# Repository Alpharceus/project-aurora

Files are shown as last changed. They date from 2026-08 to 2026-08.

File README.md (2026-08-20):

# Aurora — Wake-on-LAN over WiFi with a WT32-ETH01

Wake a sleeping PC from anywhere on your WiFi (and later, from anywhere at all)
using an inexpensive ESP32 board with a built-in Ethernet jack. Since v2 the
same board also detects your phone's presence over BLE — walk in the door
after being away and the tower wakes itself, no app running on the phone.

```
phone/laptop → WiFi → HTTP /wake?token=… → WT32-ETH01 → magic packet → PC's wired NIC
```

The WT32-ETH01 (ESP32 + LAN8720 PHY) runs both network stacks at once:
its **WiFi** side joins your home network and serves two authenticated HTTP
endpoints; its **Ethernet** side is cabled point-to-point into the PC's wired
NIC and is the only place the magic packet ever goes.

## Why this shape

- **The PC's WiFi can't do it.** Most consumer WiFi NICs have no working
  WoWLAN. The wake packet must arrive on the wired NIC.
- **Point-to-point, no switch needed.** The PC's Ethernet port connects
  directly to the board. No DHCP, no IP config on the PC side — a sleeping
  NIC matches the magic packet **in hardware at layer 2**; it never consults
  the IP stack.
- **The static-subnet trick.** The firmware pins a static subnet
  (`192.168.50.1/24`) to the ETH interface and sends the wake packet to that
  subnet's broadcast address. That forces the packet out the wire instead of
  the WiFi interface. (Stock ESPHome can't run WiFi + ETH simultaneously —
  hence plain Arduino.)
- **10/100 is fine.** NICs renegotiate down to 10/100 in sleep anyway.

## Hardware

What we actually used:

- [WT32-ETH01 board](https://www.amazon.com/dp/B0HB3B557Z) (ESP32 + LAN8720
  Ethernet)
- [CP2102 USB-UART dongles, 2-pack](https://www.amazon.com/dp/B0GWVV83SK) —
  one for the first (serial) flash, one living in a USB wall charger as the
  permanent power supply. After the first flash, updates go over WiFi (OTA)
  and the data dongle retires.
- Jumper wires, one Ethernet cable, a USB wall charger.

## Enclosure

Printable case for the WT32-ETH01: `aurora_box_body.stl` + `aurora_box_lid.stl`.
Any plastic works (ours is PLA) — plastic is transparent to both the WiFi/BLE
radio and, if you later add an mmWave sensor, its 24 GHz radar; just keep
metallic filament and foil out of the build. Leave openings for the Ethernet
jack and the power leads.

## Setup

### 1. Prepare the firmware

```
copy aurora_wake.example.ino aurora_wake/aurora_wake.ino
```

(The folder must be named `aurora_wake` — Arduino tooling requires the sketch
directory to match the sketch name.) Fill in the four values at the top:
2.4 GHz SSID + password, a long random token, and the PC's wired-NIC MAC
(`getmac /v` on Windows). **Never commit the filled-in copy** — this repo's
`.gitignore` is default-deny for that reason.

### 2. Arm the PC's NIC (Windows)

- Device Manager → the wired NIC → Power Management: allow this device to
  wake the computer, **magic packet only**.
- Advanced tab (or `Set-NetAdapterAdvancedProperty`): *Wake on Magic Packet*
  = Enabled, *Wake on pattern match* = **Disabled** (pattern wake causes
  spurious wakeups), *Shutdown Wake-On-Lan* = Enabled.
- Verify: `powercfg /devicequery wake_armed` must list the NIC.
- Disarm wake sources you don't want (we disarmed the WiFi NIC:
  `powercfg /devicedisablewake "<device name>"`), so wake attribution stays
  clean.
- Check Fast Startup is off (`HiberbootEnabled = 0`) — it breaks
  WoL-from-shutdown semantics on many systems.
- If the Ethernet port has a leftover static IP, remove it. The link needs
  **no** PC-side IP config at all, and less surface is better.

### 3. Toolchain

```
arduino-cli config init
arduino-cli config add board_manager.additional_urls https://espressif.github.io/arduino-esp32/package_esp32_index.json
arduino-cli core update-index
arduino-cli core install esp32:esp32
arduino-cli lib install NimBLE-Arduino
arduino-cli compile --fqbn esp32:esp32:wt32-eth01:PartitionScheme=min_spiffs aurora_wake
```

Two dependencies: the esp32 core (bundles `ETH.h`, `WiFi.h`, `WiFiUdp.h`,
`WebServer.h`, `ArduinoOTA.h`, `Preferences.h`, mbedtls) and NimBLE-Arduino
for the v2 presence scanning.

**The partition scheme matters and cannot change over OTA.** The default
scheme has 1.25MB app slots; the v2 sketch is ~1.29MB and won't fit. Set
`PartitionScheme=min_spiffs` (1.9MB slots) at the **first serial flash** —
if you flashed with defaults, you get exactly one more date with the UART
dongle. (Don't trust the compile output's "Maximum is 8388608 bytes" under
the default scheme — that's a boards.txt bug; the real slot is 1.25MB.)

### 4. First flash (serial — the board has no USB port)

Wiring, with the board **unpowered**:

| Dongle (data) | WT32-ETH01 |
|---|---|
| TX | **RX0** (not RXD!) |
| RX | **TX0** (not TXD!) |
| GND | GND (any GND pin) |
| 5V | **5V pin** (see gotcha #3)  |

Then: jumper **IO0 → GND**, apply power (IO0 is sampled only at power-on),
and:

```
arduino-cli upload --fqbn esp32:esp32:wt32-eth01:PartitionScheme=min_spiffs -p COM7 aurora_wake
```

Afterward: power off, remove the IO0 jumper, power on. Watch the serial line
at 115200 baud — you should see boot ROM output, dots while WiFi connects,
then the IP.

### 5. Smoke test

- `http://<board-ip>/status` → `aurora up`, firmware version, WiFi IP,
  `eth link: up/down`.
- `/wake` with no/wrong token → 403. With the token → 200 and the packet
  fires (it also self-reports if the ETH link is down).
- Give the board a **DHCP reservation** in your router so the IP never
  drifts.

### 6. Ethernet leg

Cable the board to the PC's port. `/status` should report `eth link: up` —
**including while the PC sleeps** (the NIC keeps the PHY alive). If the link
drops in sleep, revisit the NIC power settings; that's the main failure mode.

### 7. OTA from then on

```
arduino-cli compile --fqbn esp32:esp32:wt32-eth01:PartitionScheme=min_spiffs aurora_wake
arduino-cli upload --fqbn esp32:esp32:wt32-eth01:PartitionScheme=min_spiffs -p <board-ip> --upload-field password=<token> aurora_wake
```

On Windows you must allow espota inbound through the firewall once (the
*board* connects back to the *PC* to pull the binary):

```
netsh advfirewall firewall add rule name="ESP32 OTA (espota)" dir=in action=allow program="%LOCALAPPDATA%\Arduino15\packages\esp32\hardware\esp32\<ver>\tools\espota.exe" enable=yes
```

## v2: phone presence (BLE), and the auto-wake

The board passively recognizes your phone via **IRK resolution**: pair once,
and it resolves the phone's randomized Bluetooth addresses forever — no app,
no beacon, no battery cost on the phone. Arrive home after ≥10 minutes away
and the board fires the magic packet by itself.

Setup (once):

1. `GET /pair?token=…` — opens a 2-minute pairing window.
2. Pair from the phone. **Samsung/One UI hides generic BLE devices** in its
   Bluetooth-settings list, so use a BLE app (e.g. nRF Connect): scan →
   connect to `aurora` → the board demands security → Android pops the
   standard pair dialog → accept. Done; the bond survives OTA updates.
3. Watch `GET /status` — `phone: present (last seen Ns ago, X dBm)`.

Tuning via `GET /config?token=…` (persisted in NVS): `away_s` (seconds
unseen before "away", default 600), `arrival_wake` (0/1), `rssi_min`
(ignore sightings weaker than this dBm).

`GET /forget?token=…` wipes bonds for re-pairing.

**Wake attribution for downstream automation:** `/status` reports
`last_wake: <cause> <age>s ago`, where cause is `arrival` (presence fired
it) or `manual` — optionally tagged by the caller via `/wake?src=remote`
→ `manual:remote`. A host-side agent can then correlate: OS resume event
present + `arrival`, seconds old → the owner just walked in (greet);
`manual:remote` → remote access (stay quiet); packet sent but no OS resume
event → the machine was awake anyway (do nothing). The board supplies the
*why*; the OS supplies the *whether*.

Two findings worth stealing for your own build:

- **You may never see a resolvable RPA in your scan callback.** NimBLE loads
  bonded-peer IRKs into its resolving machinery, so the phone's
  advertisements arrive already resolved, bearing the *identity address*
  from pairing. Match on that identity address; keep manual `ah()` AES
  resolution only as a fallback (ours has never once fired).
- **An idle Samsung phone advertises plenty** (SmartThings Find, Fast Pair):
  presence detection worked with the phone asleep in a pocket, no app
  installed. Reports of "Android doesn't advertise when idle" did not hold
  for a current Samsung flagship.

## Every problem we actually hit (learn from our afternoon)

1. **CP2102 shows "Error, code 28" in Device Manager** — driver not
   installed. Get the Silicon Labs *CP210x Universal Windows Driver*; then it
   enumerates as a COM port.
2. **`Failed to connect to ESP32: No serial data received`** — we had the
   wires on the **TXD/RXD** pins. The boot UART is **TX0/RX0**. Crossed or
   wrong-pin serial is the cause of nearly all "dead board" reports; suspect
   wiring before hardware.
3. **The dongle's 3.3V pin cannot power this board.** The CP2102's internal
   regulator supplies ~100 mA; the ESP32 + PHY spike far beyond that when the
   radio starts. It's sneaky: **flashing works** (radio off = low current),
   then the firmware browns out invisibly at boot. Power the **5V pin** from
   USB bus power. "3.3V" in flashing guides refers to *logic levels*, not
   the power rail. And never feed 5V into the 3.3V pin.
4. **Total serial silence + no WiFi + Ethernet link down** = the board simply
   has no power. Check the red LED before debugging anything clever. (We
   spent a capture window discovering an unplugged wall dongle.)
5. **IO0 is sampled only at power-on.** Jumpering it after power is applied
   does nothing. Jumper first, then power. Any GND pin works — grounds are
   one net; the jumper doesn't need "its own" ground.
6. **Wrong WiFi credentials look identical to a dead board** — `setup()`
   blocks forever before the web server starts. The serial line (endless
   dots) is what distinguishes them.
7. **ESP32 is 2.4 GHz-only.** If your router band-steers one SSID across
   2.4/5/6 GHz, fine — but don't rename or remove the 2.4 GHz side, or the
   board is orphaned (and OTA needs WiFi: recovery means serial reflash).
   WPA3-Personal worked fine with arduino-esp32 core 3.x.
8. **Windows can't "see" the wake packets with a normal socket.** The IP
   stack drops the foreign-subnet broadcast as *not locally destined* —
   by design. To verify egress, capture at packet level (elevated):
   `pktmon filter add wol -t UDP -p 9; pktmon start --capture; …trigger…;
   pktmon stop; pktmon etl2txt …` (some pktmon builds lack `etl2pcapng`).
   Assert: 102-byte UDP broadcast, source = the board's **ETH** MAC, and no
   copy on the WiFi adapter.
9. **The NIC needs time to settle into sleep.** Entering sleep, the NIC
   renegotiates the link down to 10 Mbps; a magic packet fired during that
   window (~first 30–60 s) is silently lost. **Wait ≥60 s after sleep before
   firing** — or send the packet twice, ~10 s apart. This exact race cost us
   a test round; it will look like "WoL is flaky" when it's just timing.
10. **Wake attribution can lie.** On our ASUS board, `powercfg /lastwake`
    reports a genuine WoL wake as ACPI **"Power Button"**, while a keyboard
    wake shows as "PCI Express Root Port". Verify wakes by timing correlation
    with hands off the hardware, not by the reported device name.
11. **OTA fails with "No response from device"** after successful auth =
    Windows Firewall blocking espota's inbound transfer (see step 7).
12. **`--upload-field` belongs to `arduino-cli upload`**, not `compile` —
    two-step it when doing OTA.
13. **"aurora" won't appear in Samsung's Bluetooth pairing list.** One UI
    filters out generic BLE peripherals. Pair through nRF Connect instead,
    with the firmware calling `startSecurity()` on connect so the bond
    dialog pops regardless.
14. **`match=0` doesn't mean your IRK math is wrong.** The stack resolves
    bonded RPAs before your callback sees them — check for the identity
    address before debugging AES byte orders (we brute-forced four
    orderings before realizing the packets were pre-resolved).
15. **The away-hysteresis bites during testing:** Bluetooth must be off for
    the full `away_s` (default 10 min) before re-enabling it counts as an
    arrival. Shorter toggles do nothing, by design.
16. **The Windows-side WiFi band can shuffle after sleep cycles** (2.4 ↔
    5/6 GHz on band-steered SSIDs) — unrelated to the board, but it will
    confuse your network debugging if you don't know to look.

## Build your own companion app

We use a small Android app as the wake button; its code isn't published
because there's nothing to it — the board's HTTP API is the whole product,
and any client is ~50 lines around these rules:

- **Wake:** `GET /wake?token=<token>&src=app` — fire **twice, ~10 s apart**
  (gotcha #9: a NIC freshly entering sleep drops the first packet). The
  `src=` tag is free-form; it shows up in `/status` as `last_wake:
  manual:<src>` so downstream automation can tell your button from other
  triggers.
- **Status:** `GET /status` — plain text, one `key: value` per line; poll it
  on app open for board health, presence state, and last-wake attribution.
- **Store the token like a credential** (Android: EncryptedSharedPreferences;
  iOS: Keychain), entered by the user at first run — never hardcoded.
- **Remote reach:** no port forwarding — put the board's IP behind a
  Tailscale subnet route (a `/32` advertised by any always-on LAN device)
  and the same HTTP calls work from anywhere. One caveat: machines that are
  *already on the LAN* should not accept that route, or their traffic to the
  board detours through the relay (and OTA updates break — ask us how we
  know).

## Security model

- The token is the only gate, over plain HTTP, LAN-only. Accepted trade:
  the worst a leaked token allows is *waking the PC*.
- Nothing is exposed to the internet — no port forwarding. Remote wake goes
  through a Tailscale-connected relay host inside the LAN (a Pi, in our
  case) that curls the board.
- The board's ETH subnet is unreachable from the LAN (point-to-point island);
  a failed connect to it from the LAN is correct behavior.

## Roadmap

- LD2410 mmWave motion over UART (body-presence, complements the phone
  signal) — sensor TX → an input-only pin (35/36/39), **never IO2** (it's a
  boot-strap pin and the sensor's idle-high TX blocks the serial bootloader).
- Pi relay: one-line curl over Tailscale → full off-LAN wake. The relay
  script should fire twice ~10 s apart (gotcha #9).
- Android app: wake button + status + token storage (presence needs nothing
  on the phone, so the app stays thin).

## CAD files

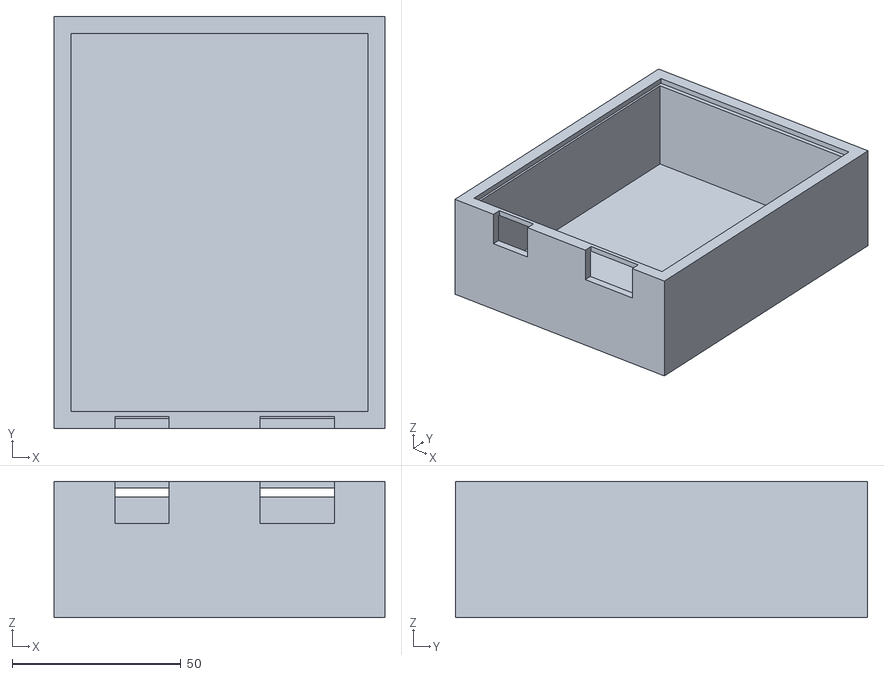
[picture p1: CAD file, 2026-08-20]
aurora_box_body.stl
98.0 x 122.0 x 40.4

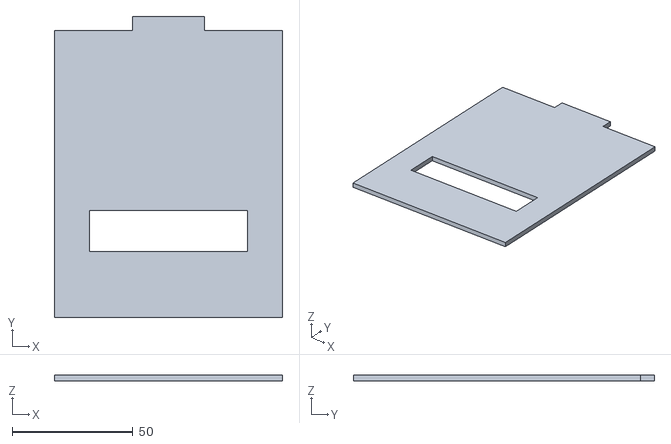
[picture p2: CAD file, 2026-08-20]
aurora_box_lid.stl
94.7 x 124.8 x 2.40

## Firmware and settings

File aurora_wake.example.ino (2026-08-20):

/*
 * Aurora — WT32-ETH01 wake device + presence sensor node (v2)
 * WiFi (STA) carries the trigger; magic packet exits the Ethernet jack
 * point-to-point into the PC's wired NIC.
 *
 * v2 additions: BLE phone presence via IRK resolution (NimBLE).
 *   - /pair?token=…   opens a 2-min pairing window; pair once from the
 *                     phone's Bluetooth settings. The phone's IRK is
 *                     captured from the bond and stored in NVS.
 *   - passive scans then resolve the phone's randomized (RPA) addresses
 *     forever after; no app needed on the phone.
 *   - arrival after >=10 min away fires the magic packet automatically.
 *   - /forget?token=… wipes bonds + IRK for re-pairing.
 * Motion (LD2410 mmWave) lands in a later OTA once the sensor is here.
 *
 * Board: WT32-ETH01 (arduino-esp32 core; FQBN
 *   esp32:esp32:wt32-eth01:PartitionScheme=min_spiffs — v2 needs the
 *   1.9MB app slots; partition scheme was set at the Aug 15 serial flash.)
 */

// ---------- fill these in ----------
const char* WIFI_SSID   = "YOUR_SSID";        // 2.4 GHz network (ESP32 has no 5/6 GHz radio)
const char* WIFI_PASS   = "YOUR_PASS";
const char* WAKE_TOKEN  = "pick-a-long-random-string";
// Target PC's wired-NIC MAC, from `getmac /v` (format: AA:BB:CC:DD:EE:FF)
const uint8_t PC_MAC[6] = { 0xAA, 0xBB, 0xCC, 0xDD, 0xEE, 0xFF };
const char* FW_VERSION  = "2.3";
// -----------------------------------

// Presence tuning — runtime-adjustable via /config, persisted in NVS
uint32_t cfgAwayS       = 600;   // unseen this many seconds -> away
bool     cfgArrivalWake = true;  // fire magic packet on arrival
int      cfgRssiMin     = -100;  // ignore sightings weaker than this (dBm)
const uint32_t PAIR_WINDOW_MS = 2UL * 60UL * 1000UL;   // /pair advertising window

// WT32-ETH01 PHY wiring (must be defined before ETH.h)
#define ETH_PHY_TYPE  ETH_PHY_LAN8720
#define ETH_PHY_ADDR  1
#define ETH_PHY_MDC   23
#define ETH_PHY_MDIO  18
#define ETH_PHY_POWER 16
#define ETH_CLK_MODE  ETH_CLOCK_GPIO0_IN

#include <ETH.h>
#include <WiFi.h>
#include <WiFiUdp.h>
#include <WebServer.h>
#include <ArduinoOTA.h>
#include <Preferences.h>
#include <NimBLEDevice.h>
#include <mbedtls/aes.h>
#include "nimble/nimble/host/include/host/ble_store.h"

// Point-to-point subnet on the wire. Nothing else lives here; the
// broadcast address pins the packet's route to the ETH interface.
IPAddress ETH_IP(192, 168, 50, 1);
IPAddress ETH_GW(192, 168, 50, 1);
IPAddress ETH_MASK(255, 255, 255, 0);
IPAddress ETH_BCAST(192, 168, 50, 255);

WebServer server(80);
WiFiUDP udp;
Preferences prefs;

// ---- presence state (written from NimBLE host task, read in loop task) ----
uint8_t  phoneIRK[16];
bool     haveIRK      = false;
uint8_t  idAddr[6];              // phone's identity address (post-resolution)
bool     haveIdAddr   = false;
volatile bool     phonePresent = false;
volatile uint32_t lastSeenMs   = 0;
volatile bool     everSeen     = false;
volatile int      lastPhoneRssi = 0;
volatile uint32_t cntAdv = 0, cntRpa = 0, cntMatch = 0, cntArrivalWakes = 0;
volatile uint32_t cntIdMatch = 0;
bool     pairingOpen  = false;
uint32_t pairWindowEnd = 0;

// Why the last magic packet was sent — Orion reads this from /status after
// a resume and decides greet / stay dormant / warn.
char     lastWakeCause[24] = "none";
volatile uint32_t lastWakeMs   = 0;
volatile bool     haveLastWake = false;

static void recordWake(const char* cause) {
  strncpy(lastWakeCause, cause, sizeof(lastWakeCause) - 1);
  lastWakeCause[sizeof(lastWakeCause) - 1] = 0;
  lastWakeMs = millis();
  haveLastWake = true;
}

void sendMagicPacket() {
  uint8_t pkt[102];
  memset(pkt, 0xFF, 6);
  for (int i = 1; i <= 16; i++) memcpy(pkt + i * 6, PC_MAC, 6);
  // Send a burst; WoL is fire-and-forget and repeats are free.
  for (int i = 0; i < 3; i++) {
    udp.beginPacket(ETH_BCAST, 9);
    udp.write(pkt, sizeof(pkt));
    udp.endPacket();
    delay(50);
  }
}

// ---- IRK / RPA resolution ------------------------------------------------
// BT spec: RPA(48b) = prand(24 MSB) | hash(24 LSB); hash = ah(IRK, prand),
// ah = AES128(k, 0^104 | prand) mod 2^24. Addresses arrive little-endian:
// addr[0..2] = hash, addr[3..5] = prand, (addr[5] & 0xC0) == 0x40 marks RPA.
// IRK byte order out of the bond store varies by stack; check both.
static bool ahMatches(const uint8_t* key /*big-endian for mbedtls*/,
                      const uint8_t* addr) {
  uint8_t in[16] = {0};
  in[13] = addr[5]; in[14] = addr[4]; in[15] = addr[3];  // prand, MSB first
  uint8_t out[16];
  mbedtls_aes_context aes;
  mbedtls_aes_init(&aes);
  mbedtls_aes_setkey_enc(&aes, key, 128);
  mbedtls_aes_crypt_ecb(&aes, MBEDTLS_AES_ENCRYPT, in, out);
  mbedtls_aes_free(&aes);
  return out[15] == addr[0] && out[14] == addr[1] && out[13] == addr[2];
}

static bool rpaMatchesIrk(const uint8_t* addr) {
  if (ahMatches(phoneIRK, addr)) return true;   // IRK as stored
  uint8_t rev[16];
  for (int i = 0; i < 16; i++) rev[i] = phoneIRK[15 - i];
  return ahMatches(rev, addr);                  // reversed byte order
}

static void onPhoneSighted(int rssi) {
  if (rssi < cfgRssiMin) return;   // too faint to count as "here"
  lastPhoneRssi = rssi;
  uint32_t now = millis();
  bool arriving = !phonePresent;   // covers boot (unknown) and away-timeout
  lastSeenMs = now;
  everSeen = true;
  phonePresent = true;
  if (arriving && cfgArrivalWake) {
    sendMagicPacket();             // wake on an awake PC is a harmless no-op
    recordWake("arrival");
    cntArrivalWakes++;
  }
}

// ---- BLE callbacks -------------------------------------------------------
class ScanCB : public NimBLEScanCallbacks {
  void onResult(const NimBLEAdvertisedDevice* d) override {
    cntAdv++;
    const NimBLEAddress a = d->getAddress();
    const uint8_t* v = a.getVal();
    uint8_t t = a.getType();
    // Path 1: the stack already resolved a bonded peer's RPA — the report
    // carries the identity address we captured at pairing.
    if (haveIdAddr && memcmp(v, idAddr, 6) == 0) {
      cntIdMatch++;
      onPhoneSighted(d->getRSSI());
      return;
    }
    // Path 2: unresolved RPA — resolve manually against the stored IRK.
    if (!haveIRK) return;
    if (t != BLE_ADDR_RANDOM) return;
    if ((v[5] & 0xC0) != 0x40) return;          // not an RPA
    cntRpa++;
    if (rpaMatchesIrk(v)) {
      cntMatch++;
      onPhoneSighted(d->getRSSI());
    }
  }
  void onScanEnd(const NimBLEScanResults&, int) override {
    NimBLEDevice::getScan()->start(0, false, true);  // never stop scanning
  }
};
static ScanCB scanCB;

static void startPresenceScan() {
  NimBLEScan* s = NimBLEDevice::getScan();
  s->setScanCallbacks(&scanCB, false);
  s->setActiveScan(false);        // passive: never transmit, just listen
  s->setInterval(300);            // lazy duty cycle so WiFi HTTP stays snappy
  s->setWindow(40);
  s->setDuplicateFilter(false);   // every sighting must refresh lastSeen
  s->setMaxResults(0);            // callback-only, store nothing
  s->start(0, false, true);
}

class SrvCB : public NimBLEServerCallbacks {
  void onConnect(NimBLEServer*, NimBLEConnInfo& info) override {
    // Demand pairing on any connection — pops the bond dialog on the
    // phone even when its settings app hides us (Samsung One UI filter).
    NimBLEDevice::startSecurity(info.getConnHandle());
  }
  void onAuthenticationComplete(NimBLEConnInfo& info) override {
    // Bonding done — pull the peer's IRK out of the NimBLE bond store.
    const NimBLEAddress id = info.getIdAddress();
    ble_store_key_sec k = {};
    k.peer_addr.type = id.getType();
    memcpy(k.peer_addr.val, id.getVal(), 6);
    ble_store_value_sec v = {};
    if (ble_store_read_peer_sec(&k, &v) == 0 && v.irk_present) {
      memcpy(phoneIRK, v.irk, 16);
      haveIRK = true;
      prefs.putBytes("irk", phoneIRK, 16);
    }
    memcpy(idAddr, id.getVal(), 6);
    haveIdAddr = true;
    prefs.putBytes("ida", idAddr, 6);
    NimBLEDevice::getServer()->disconnect(info.getConnHandle());
  }
};
static SrvCB srvCB;

static bool openPairingWindow() {
  NimBLEDevice::getScan()->stop();
  NimBLEAdvertising* adv = NimBLEDevice::getAdvertising();
  // Android's pairing screen only lists devices that advertise as general
  // discoverable with a name — set both explicitly, plus a scan response.
  NimBLEAdvertisementData ad;
  ad.setFlags(BLE_HS_ADV_F_DISC_GEN | BLE_HS_ADV_F_BREDR_UNSUP);
  ad.setName("aurora");
  adv->setAdvertisementData(ad);
  NimBLEAdvertisementData sr;
  sr.setName("aurora");
  adv->setScanResponseData(sr);
  bool ok = adv->start();
  pairingOpen = ok;
  pairWindowEnd = millis() + PAIR_WINDOW_MS;
  return ok;
}

static void closePairingWindow() {
  NimBLEDevice::getAdvertising()->stop();
  pairingOpen = false;
  startPresenceScan();
}

// ---- HTTP handlers -------------------------------------------------------
static bool tokenOk() {
  return server.hasArg("token") && server.arg("token") == WAKE_TOKEN;
}

void handleWake() {
  if (!tokenOk()) { server.send(403, "text/plain", "no"); return; }
  sendMagicPacket();
  // Callers may self-identify (/wake?src=remote, src=app) for attribution.
  char cause[24] = "manual";
  if (server.hasArg("src")) {
    String src = server.arg("src");
    char clean[13] = {0};
    int n = 0;
    for (size_t i = 0; i < src.length() && n < 12; i++)
      if (isalnum(src[i]) || src[i] == '-' || src[i] == '_') clean[n++] = src[i];
    if (n > 0) snprintf(cause, sizeof(cause), "manual:%s", clean);
  }
  recordWake(cause);
  server.send(200, "text/plain",
              ETH.linkUp() ? "magic packet sent"
                           : "sent, but ETH link is DOWN - check cable");
}

void handlePair() {
  if (!tokenOk()) { server.send(403, "text/plain", "no"); return; }
  if (openPairingWindow()) {
    server.send(200, "text/plain",
                "pairing window open for 2 min - pair 'aurora' from the "
                "phone's Bluetooth settings now");
  } else {
    server.send(500, "text/plain", "advertising failed to start");
  }
}

void handleForget() {
  if (!tokenOk()) { server.send(403, "text/plain", "no"); return; }
  NimBLEDevice::deleteAllBonds();
  prefs.remove("irk");
  prefs.remove("ida");
  haveIRK = false;
  haveIdAddr = false;
  phonePresent = false;
  everSeen = false;
  server.send(200, "text/plain", "bonds and IRK wiped - /pair to re-pair");
}

void handleConfig() {
  if (!tokenOk()) { server.send(403, "text/plain", "no"); return; }
  if (server.hasArg("away_s")) {
    long v = server.arg("away_s").toInt();
    if (v >= 30 && v <= 86400) { cfgAwayS = v; prefs.putUInt("away_s", cfgAwayS); }
  }
  if (server.hasArg("arrival_wake")) {
    cfgArrivalWake = server.arg("arrival_wake").toInt() != 0;
    prefs.putBool("arr_wake", cfgArrivalWake);
  }
  if (server.hasArg("rssi_min")) {
    long v = server.arg("rssi_min").toInt();
    if (v >= -100 && v <= 0) { cfgRssiMin = v; prefs.putInt("rssi_min", cfgRssiMin); }
  }
  String s = "away_s: " + String(cfgAwayS) + "\n";
  s += "arrival_wake: " + String(cfgArrivalWake ? 1 : 0) + "\n";
  s += "rssi_min: " + String(cfgRssiMin) + "\n";
  server.send(200, "text/plain", s);
}

void handleStatus() {
  uint32_t now = millis();
  String s = "aurora up\n";
  s += "ver: " + String(FW_VERSION) + "\n";
  s += "wifi: " + WiFi.localIP().toString() + "\n";
  s += "rssi: " + String(WiFi.RSSI()) + " dBm\n";
  s += "eth link: " + String(ETH.linkUp() ? "up" : "down") + "\n";
  s += "heap: " + String(ESP.getFreeHeap()) + " free\n";
  if (pairingOpen) {
    s += "phone: pairing window open (" +
         String((pairWindowEnd - now) / 1000) + "s left)\n";
  } else if (!haveIRK) {
    s += "phone: not paired (/pair to set up)\n";
  } else if (!everSeen) {
    s += "phone: paired, never seen since boot\n";
  } else {
    s += "phone: " + String(phonePresent ? "present" : "away");
    s += " (last seen " + String((now - lastSeenMs) / 1000) + "s ago, ";
    s += String(lastPhoneRssi) + " dBm)\n";
  }
  s += "motion: no sensor\n";
  if (haveLastWake) {
    s += "last_wake: " + String(lastWakeCause) + " " +
         String((now - lastWakeMs) / 1000) + "s ago\n";
  } else {
    s += "last_wake: none\n";
  }
  s += "ble: adv=" + String(cntAdv) + " rpa=" + String(cntRpa) +
       " match=" + String(cntMatch) + " id_match=" + String(cntIdMatch) +
       " arrival_wakes=" + String(cntArrivalWakes) + "\n";
  server.send(200, "text/plain", s);
}

void setup() {
  Serial.begin(115200);

  prefs.begin("aurora");
  if (prefs.getBytesLength("irk") == 16) {
    prefs.getBytes("irk", phoneIRK, 16);
    haveIRK = true;
  }
  if (prefs.getBytesLength("ida") == 6) {
    prefs.getBytes("ida", idAddr, 6);
    haveIdAddr = true;
  }
  cfgAwayS       = prefs.getUInt("away_s", cfgAwayS);
  cfgArrivalWake = prefs.getBool("arr_wake", cfgArrivalWake);
  cfgRssiMin     = prefs.getInt("rssi_min", cfgRssiMin);

  ETH.begin();
  ETH.config(ETH_IP, ETH_GW, ETH_MASK);

  WiFi.mode(WIFI_STA);
  WiFi.setHostname("aurora");      // name shown by the router's device list
  WiFi.setSleep(false);            // keep HTTP latency low
  WiFi.begin(WIFI_SSID, WIFI_PASS);
  while (WiFi.status() != WL_CONNECTED) { delay(250); Serial.print("."); }
  Serial.printf("\nWiFi: %s\n", WiFi.localIP().toString().c_str());

  ArduinoOTA.setHostname("aurora");
  ArduinoOTA.setPassword(WAKE_TOKEN);  // reuse; or set a separate one
  ArduinoOTA.begin();

  server.on("/wake", handleWake);
  server.on("/status", handleStatus);
  server.on("/pair", handlePair);
  server.on("/forget", handleForget);
  server.on("/config", handleConfig);
  server.begin();

  // BLE last, once the wake path is already serving.
  NimBLEDevice::init("aurora");
  NimBLEDevice::setSecurityAuth(true /*bond*/, false /*mitm*/, true /*sc*/);
  NimBLEDevice::setSecurityInitKey(BLE_SM_PAIR_KEY_DIST_ENC |
                                   BLE_SM_PAIR_KEY_DIST_ID);
  NimBLEDevice::setSecurityRespKey(BLE_SM_PAIR_KEY_DIST_ENC |
                                   BLE_SM_PAIR_KEY_DIST_ID);
  NimBLEServer* srv = NimBLEDevice::createServer();
  srv->setCallbacks(&srvCB);
  // Bond may predate this build — recover the identity address from the store.
  if (!haveIdAddr && NimBLEDevice::getNumBonds() > 0) {
    NimBLEAddress b = NimBLEDevice::getBondedAddress(0);
    memcpy(idAddr, b.getVal(), 6);
    haveIdAddr = true;
    prefs.putBytes("ida", idAddr, 6);
  }
  startPresenceScan();
}

void loop() {
  server.handleClient();
  ArduinoOTA.handle();

  uint32_t now = millis();
  if (pairingOpen && (int32_t)(now - pairWindowEnd) >= 0) closePairingWindow();
  if (phonePresent && now - lastSeenMs > cfgAwayS * 1000UL) phonePresent = false;
}

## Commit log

2026-08-14 Initial public release: WT32-ETH01 WoL-over-WiFi wake device
    Sanitized template sketch, full setup guide, and the complete list of
    pitfalls hit during hardware validation (serial pins, power, PHY settle
    race, wake attribution, OTA firewall).
    Claude-Session: https://claude.ai/code/session_01CBGQdqn9dC8jFpiYBjgtRs
2026-08-14 README: note that all sketch includes ship with the esp32 core
    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
2026-08-16 v2.1: BLE phone presence with arrival auto-wake
    IRK pairing via /pair window, passive identity-address matching (NimBLE
    resolves bonded RPAs in-stack), 10-min away hysteresis, runtime /config
    (away_s, arrival_wake, rssi_min in NVS). README gains the presence
    chapter, min_spiffs partition requirement, and gotchas 13-16.
    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
    [aurora_wake.example.ino]
2026-08-20 Add printable enclosure (body + lid STLs)
    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
    [aurora_box_body.stl, aurora_box_lid.stl]
